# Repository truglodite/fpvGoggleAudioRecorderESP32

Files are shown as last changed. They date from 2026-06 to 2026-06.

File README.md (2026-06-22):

# fpvGoggleAudioRecorderESP32
## An easy to use reliable audio recording device for FPV goggles

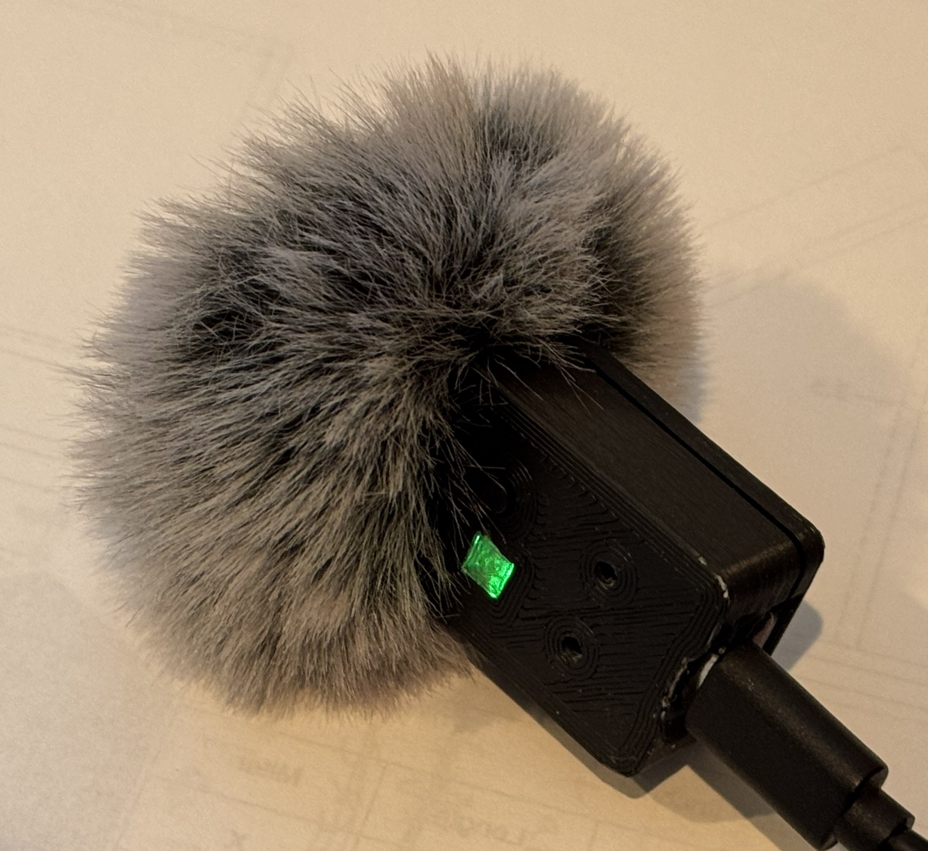
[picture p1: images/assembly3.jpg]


### Features:
- Easy to use "plug and forget" fully automated recording to sd card
- Powered via goggle USB charging jack
- 24bit-44khz audio pipeline
- DSP filter with RMS AGC and clipping limiter (pre-tuned, user adjustable)
- Robust and efficient dual core separated audio and sd write engines
- Corruption resistant raw PCM recording format and sd write methods
- "Start new segment file" button
- Easy to use Raw->Wav file converter app for PC
- Compact printable enclosure

### Hardware:
*Prefer no pins installed if using the printable enclosure*
- ESP32 S3 Super Mini Board: https://www.amazon.com/dp/B0GFDSK5RD
- ICS43434 I2S Microphone Board: https://www.amazon.com/ICS43434-Microphone-Breakout-Module-Filter/dp/B0FMDGRM8F
    * Note that almost any i2s mic (like INMP441) could be substituted in place of an ICS43434. The ICS mic is recommended as it has high dynamic range and sensitivity for the price point. Also the printed enclosure is designed to fit the above linked ICS mic board (square, not round style).
- Micro SD Card Board (3.3V): https://www.amazon.com/WWZMDiB-Module-Adapter-Memory-Shield/dp/B0BV8ZQ81F
    * I recommend removing the 4 resistors on the SD card board. Leaving the resistors on may cause problems with certain SD cards.
- 6mm Momentary NO Tactile Button: https://www.amazon.com/Momentary-Tactile-Through-Breadboard-Friendly/dp/B07WF76VHT
- 10mm Microphone Wind Screen: https://www.amazon.com/dp/B07BQ2LZDX
- SD card: https://www.amazon.com/dp/B07FCMBLV6
    * A high quality A2/U3 rated SD card is highly recommended for trouble free operation. Sandisk Extreme or Samsung Pro Plus have been tested and work well. These SD cards are generally shipped with exFAT formatting, which will not work with this project. The SD card must be formatted to fat32.

### Operation
Simply plug a USB-C to USB-C cable between the recorder and your goggle charging jack, and fly as usual. This has been tested with DJI goggles 1, 2, and 3. Fully automated recording should also work with any goggles that output 5V only while turned on.

Audio will start recording when you power on your goggles, and recording will stop when you power them off. If you want to start a new segment file while recording, click the button. This can be useful if for example you have to wait a while for GPS satellites before launching. Then less jogging is required for A/V sync in your editor.

The code makes use of the onboard LED to indicate status. A blue LED to indicates boot status immediately after powering on. While recording, a green pulsating LED with an occasional red LED will indicate normal recording and clipping limiter operation. After a button press, a blue LED will briefly light to indicate a the current segment file is closed and a new segment file is started. A repeated flashing red led indicates a failure (usually the SD card has come loose or otherwise failed). An orange flashing LED indicates the audio buffer is falling behind (extremely rare).

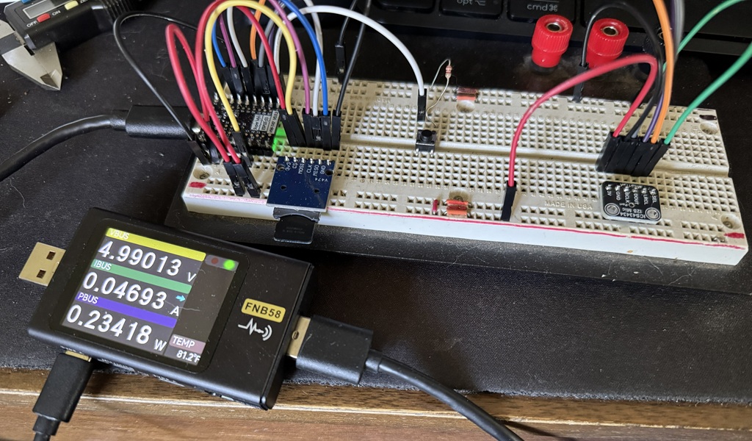
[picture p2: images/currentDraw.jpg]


The circuit averages ~50mA current draw while recording. Operating the recorder with a standard goggle battery will not appreciably decrease run time.

### Recording Format:
Similar to how a dashcam/bodycam works, this code records audio to 24bit 44khz raw PCM files which are not prone to corruption on sudden power loss. When power is cutoff, typically only the last 0-200msec of audio are lost; in a rare worst case event the last ~1.7sec may be lost. The files are named "rec_X-Y.24bit.raw", where X is the recording session, and Y is the audio segment. Both X and Y increment to allow sequential reconstruction recordings. A new segment file is created within a session after every ~2min of recording, or after the new segment file button is pressed. Code design ensures no gaps in audio between segment files. New sessions are created after power cycles.

The code makes use of a DSP filter with HPF, RMS audio compressor, and clipping limiter, which are tuned for recording "ambient voice and noise". Users can modify DSP parameters to suit their specific needs by editing values of the 7 `#defines` located at the top of the code. These parameters have comments on usage for those not familiar with DSP technical details. In general the tuning the DSP will involve balancing distant noises with background hiss to suit personal tastes.

### Post Processing:
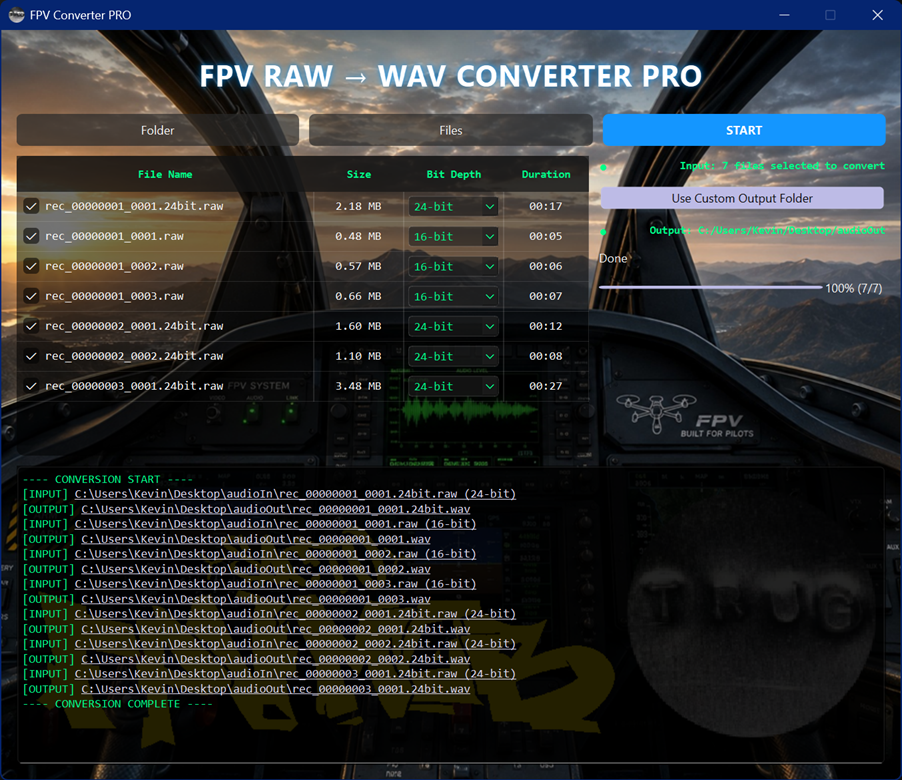
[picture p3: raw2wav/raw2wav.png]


For convenience I created `raw2wav.exe`, a Windows executable that converts batches of raw files recorded with the fpvGoggleAudioRecorderESP32 into easy to use wav files (raw2wav.exe, in raw2wav/dist/). To use the converter, run the `raw2wav.exe`, select the input folder (your SD card) and optionally an output folder. If any of the loaded files do not need conversion, uncheck the box next to them in the file selector area. Click the "Start" button to convert the selected files. The log area near the bottom shows which files are being converted and where the converted files are saved. You can click an output path in the log area to open the output folder in explorer. 

The input file list has drop down boxes for audio resolution. 16bit is there for my older RP2040 based goggle recorder project. The app will automatically select the correct 16bit or 24bit resolution based on the presence or absence of "24bit" in the filename.

Note that raw2wav.exe does not actually modify the audio content; it simply adds wav headers to the raw data and saves the files with a `*.wav` extension. Alternatively, you can do your conversions using a program like Audacity to "import raw data", "24bit unsigned", "little endian", "mono", with "44100hz" bit rate, and export to a wav file. If you do not want to use the included executable, you can compile the source using python. The compile command I used is written at the top of `raw2wav.py`.

### Logging:
A `manifest.log` file is saved to the sd card for troubleshooting purposes. Below is an example of lines that may be appended to the log (note that CLOSE and METADATA lines are written only when either a segment last longer than ~2min, or when the new segment button is used):

```
OPEN,/rec_00000001_0001.24bit.raw,12405
CLOSE,/rec_00000001_0001.24bit.raw,132405
METADATA,/rec_00000001_0001.24bit.raw,PEAK=7842100,OVERRUNS=0,AVG_QUEUE=1.42,POOL_LEAKS=0,16586
```

- OPEN/CLOSE: The millisecond timer value when a segment file starts or stops. Calculating sequential `OPEN time - CLOSE time` can help diagnose time stretching/drifting within a file (often caused by overheating or an imprecise XTAL oscillator). Similarly, sequential file `CLOSE time - OPEN time` calculation can pinpoint recording "blind spots" between files (typically caused by poor SD card performance).
- PEAK: Tells you the highest 24bit dynamic audio level recorded in that file segment ($0$ to $8,388,607$). During typical use this should be roughly `2000000` to `6000000`, indicating proper AGC tuning for the application. If this value is very low (`~300,000`) or high (`~8000000`), it indicates poor utilization of the available dynamic range from the audio engine. Your DSP parameters (or choice of mic) may not be well suited to your application, and tweaking these items may help.
- OVERRUNS: The number of dropped audio blocks. This value should remain 0. Consistent non-zero values indicate an out of spec (not A2/U3) SD card that is struggling to keep up with sustained writes.
- AVG_QUEUE: Represents the running average depth of the queue over time. A healthy value sits between 0.5 and 2.0. If this numbers climbs up to 15.0 or 30.0 on a file, it indicates high SD card write latency, which may affect the reliability of recordings.
- POOL_LEAKS: The number of audio core crashes. This should remain zero. This part contains 2 values, X,Y. X represents the number of audio core crashes that resulted in a lost audio block, and Y is the total number of blocks that have passed through the capture queue. Similar to OVERRUNS, a non-zero X indicates a slow or defective SD card. POOL_LEAKS can also indicate very high DSP overhead; this has not been observed with the default DSP configuration and range of parameters recommended in the code comments.

### Flashing/Compiling:
I recommend using VSCode with the PlatformIO extension to compile and upload this code to your ESP32 board. Download and unzip this repo to your `Projects` folder. Use the "Open Project" button in PlatformIO home and select the `fpvgoggleaudiorecorderesp32-main` folder. Connect your esp32 to a USB port on your PC, and click the upload button to compile and upload the firmware to your ESP32 (right arrow button on the bottom bar in VSCode). Further details on setting up and using PlatformIO are beyond the scope this repo.

### Wiring:
Connect the hardware together as shown in the table below.

Device  |   Pin |   ESP32 Pin
----|-----|----
MIC |   SEL |   GND
MIC |   LRCL |   4
MIC |   BCLK |   5
MIC |   DOUT |   6
MIC |   GND |   GND
MIC |   3V |   3v3
SD |   GND |   GND
SD |   MISO |   1
SD |   MOSI |   2
SD |   CLK |   3
SD |   CS |   10
SD |    3v3 |   3v3
BUTT |   A |   7
BUTT |   B  |   GND

### Printable Enclosure:

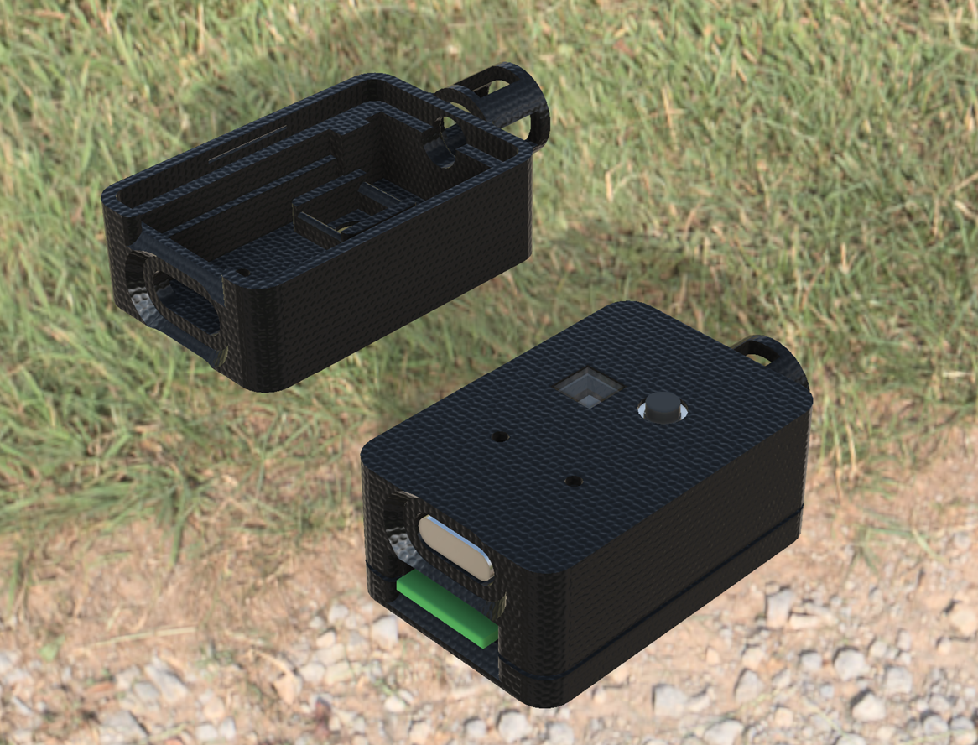
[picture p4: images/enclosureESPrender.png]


Files for a printable enclosure are provided in this repo. One of each part should be printed. Print the "agcRecorderTopWindscreen.stl" if you want to use a 10mm foam or furry wind screen on your mic. ABS or PETG is recommended for the top, bottom, and shim. Clear PETG filament or clear SLA resin should be used for the lens. I recommend using T-7000 adhesive on all of the glue joints described below.

Test fit all of the parts before wiring and assembling with glue. Make sure you can fit a toothpick or similar insulated rod through the 2 button access holes on the top of the case; cut them larger if needed. Break off the unused pins on one side of your button to prevent shorting. Insert the button into the enclosure top with pins facing the mic hole. Insert the lens into the square hole next to the button. Insert the mic board into the enclosure top, pin holes first, with the mic hole facing outward. Insert the ESP32 board into the enclosure top. Insert the SD card into it's spot on the bottom of the case, with the bare side of the board pointing downward. Snap the top and bottom halves together, making sure they fully engage. There should be a ~0.5mm gap bewteen them when fully seated. If this gap is crooked or too large, adjust fit/reprint as needed. If everything fits well, disassemble and move on to wiring.

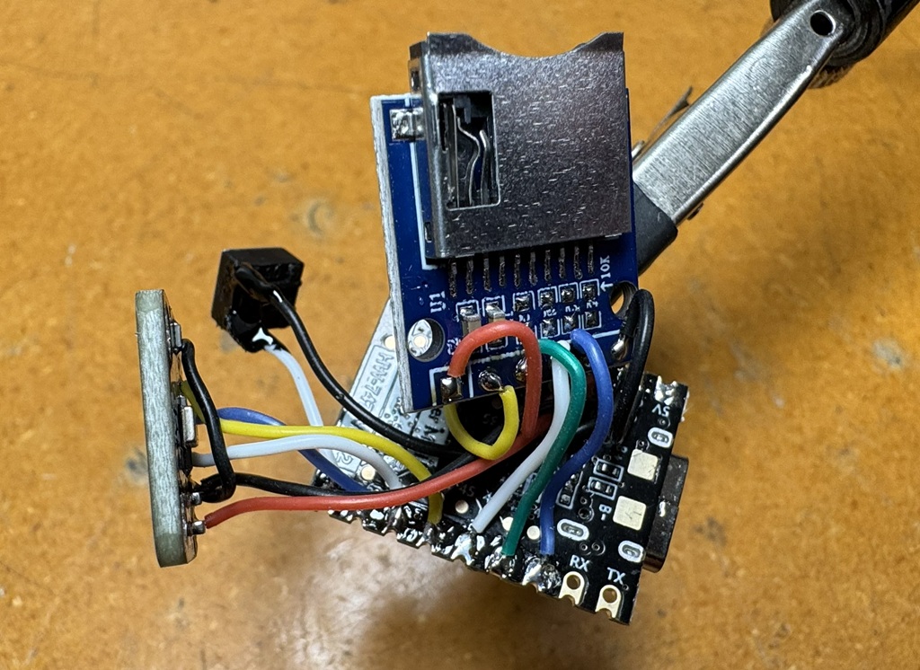
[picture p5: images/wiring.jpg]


Tidy wire routing is important as the enclosure is compact. Silicone stranded 30awg wire or smaller is recommended. Cut the wires long enough to permit assembly without tension, but not so long that assembly may pinch a wire. Start with soldering wires to the back side of the ESP32 board (opposite of boot/reset buttons). The 3 GND wires and 2 3v3 wires can be solder on the larger pads of the ESP32; it's easiest to strip and twist these wires together before tinning and soldering the bundles on the pads. Cut/solder wires to the button pins and coat the joints with glue. Cut/solder wires to the chip side of the microphone, adding a short jumper wire between the SEL and GND pins. Cut/solder wires to the top (card side) of the SD card board. Power up the circuit and verify proper operation after soldering is complete. If it records audio properly, proceed with the rest of the assembly.

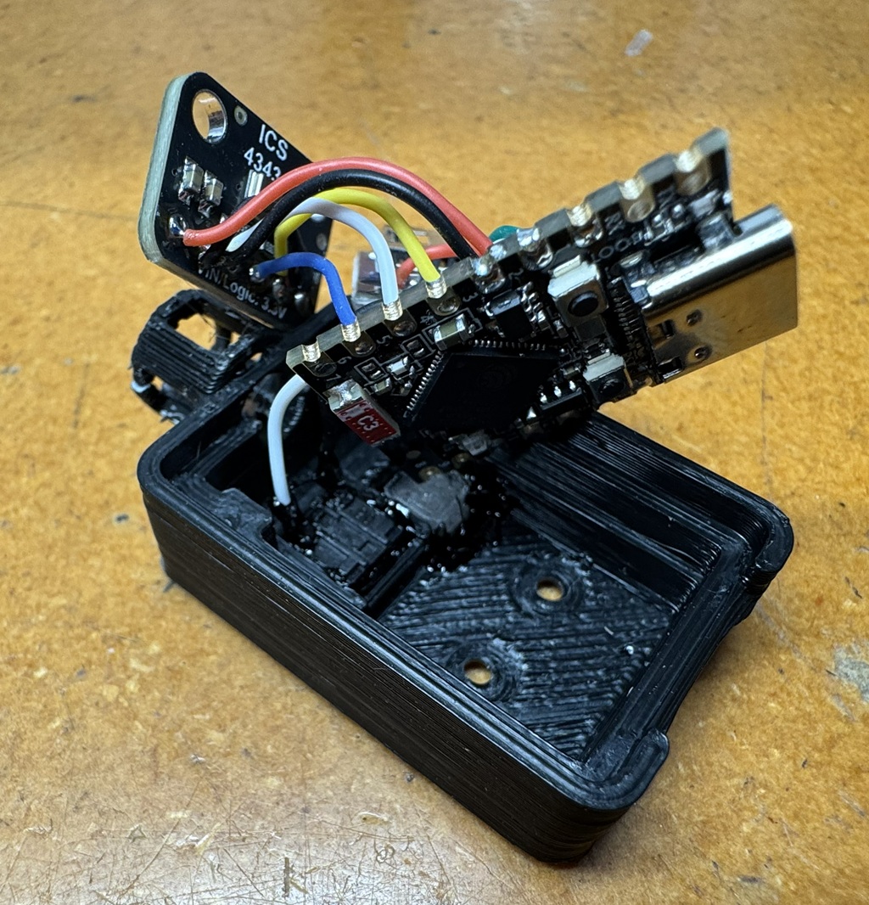
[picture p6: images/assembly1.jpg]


 First add a fillet of glue around the inside edges of the lens you pressed in earlier. Next glue the button into place; use a small amount at first to avoid squirt out that may interfere with operation. Hold the button firmly in position until the glue tacks up. Add glue to the rails where the ESP32 will sit, and press the ESP into the rails. Add a fillet of additional glue on top of the board where it touches the rails, and hold it in place until the glue tacks up. Repeat this procedure to glue the SD card in the bottom half of the case. Insert the mic into the top half of the case, adding a small amount of glue to the rails to prevent movement. Now snap the case halves together taking care not to pinch any wires. Finally, add a thick bead of glue around the bottom of the windscreen basket where it touches the box and install the windscreen, pressing it firmly down into the glue.

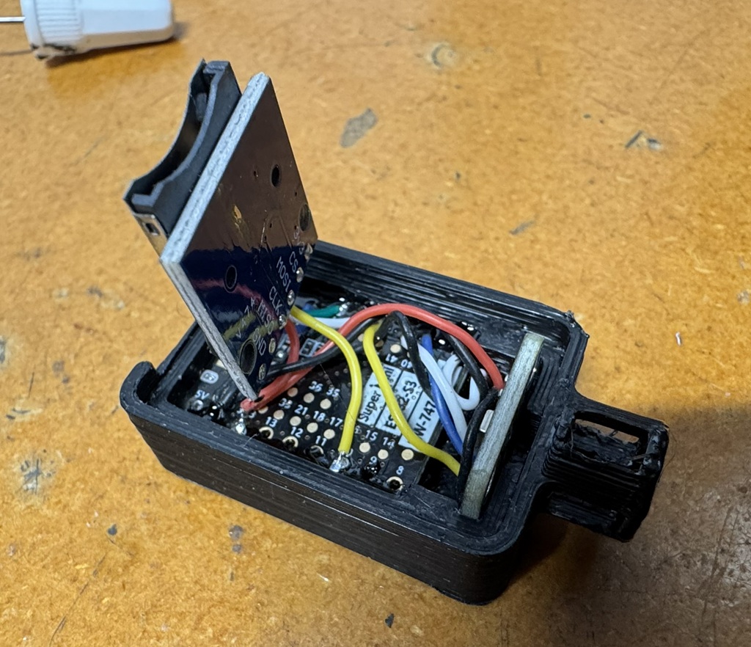
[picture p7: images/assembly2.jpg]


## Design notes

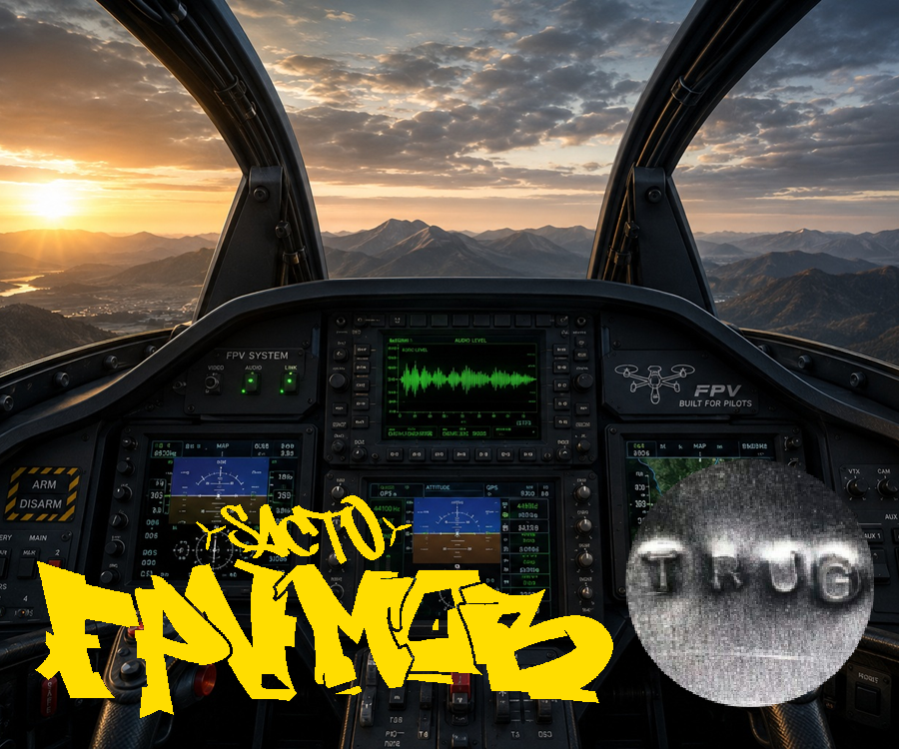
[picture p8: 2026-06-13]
raw2wav/background.png

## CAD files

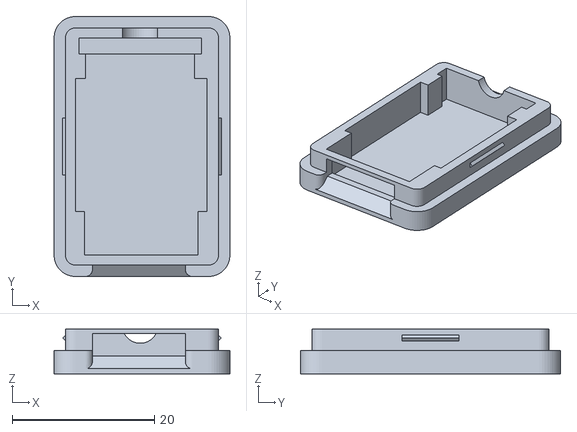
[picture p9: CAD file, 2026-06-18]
enclosure/fpvGoggleAudioRecorderESPbottom.stl
24.7 x 36.6 x 6.29

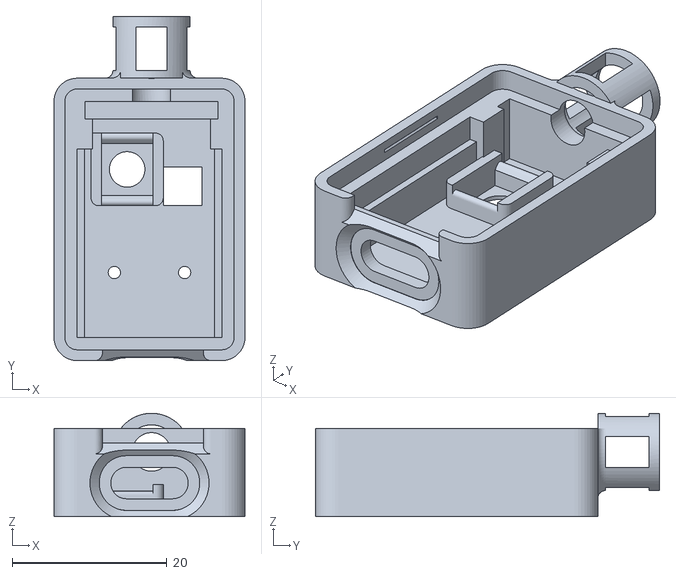
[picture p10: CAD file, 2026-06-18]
enclosure/fpvGoggleAudioRecorderESPtop.stl
24.7 x 44.6 x 13.4

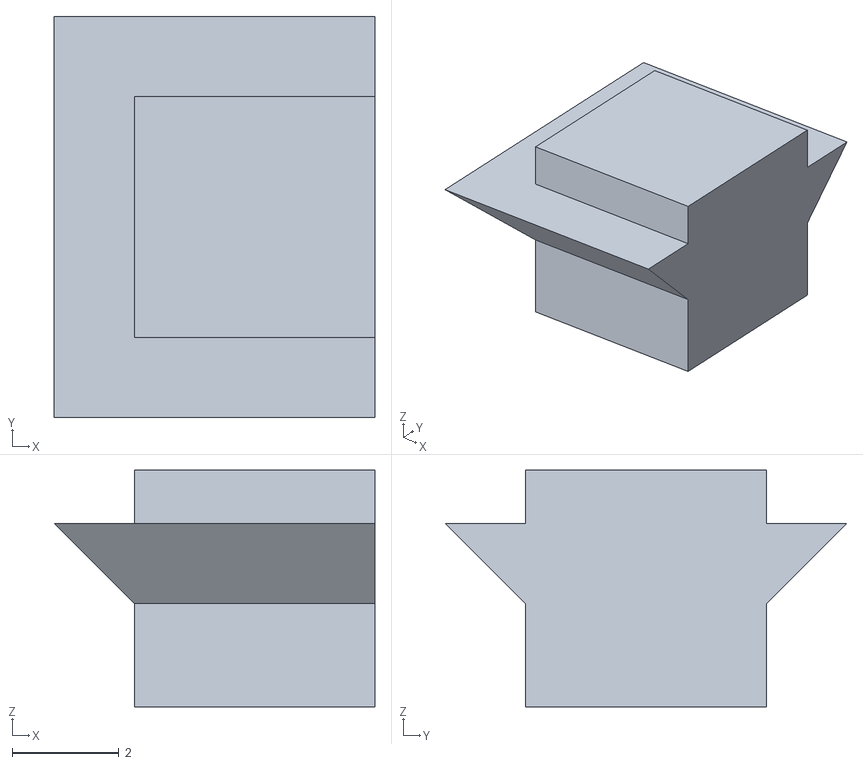
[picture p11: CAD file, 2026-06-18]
enclosure/fpvGoggleAudioRecorderESPlens.stl
6.00 x 7.50 x 4.43

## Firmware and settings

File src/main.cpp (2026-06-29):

/*
    fpvGoggleAudioRecorderESP32
    Production-oriented FPV goggle audio recorder

    Hardware:
    - ESP32-S3 Super Mini (v0.02 4MB Flash Revision)
    - ICS43434 I2S microphone (True 24-bit Audio Capture)
    - SPI microSD Slot (Configured on 100% safe edge pins)
    - Momentary Segment Button on GPIO 7 (Active Low, Internal Pullup)
    - Onboard WS2812 RGB LED on GPIO 48 (Hardware Driven via Freenove)

    Audio Architecture:
    - Dedicated FreeRTOS Audio Task pinned strictly to Core 1 (APP_CPU)
    - Disk Writing, File Operations, and UI handling locked to Core 0 (PRO_CPU)
    - Format: RAW 24-bit PCM, Signed little-endian (3 Bytes per sample), 44100 Hz mono
    - Hardware Floating-Point Unit (FPU) Optimized DSP chain
*/

#include <Arduino.h>
#include <SPI.h>
#include <SD.h>
#include <driver/i2s.h>
#include <Freenove_WS2812_Lib_for_ESP32.h>
#include <math.h>
#include <atomic>

// ======================================================
// DSP & AGC (AUTOMATIC GAIN CONTROL) CONFIGURATION
// ======================================================

// High-Pass Filter cutoff frequency in Hz.
// The alpha coefficient is derived as expf(-2π·fc/fs) — exact 1st-order RC HPF.
// [Recommended Range: 35.0f to 140.0f Hz]
// - 35.0f:  Very gentle cut (~0.995 alpha). Lets wind rumble through.
// - 85.0f:  Standard vocal mic cutoff. Blocks breath plosives. (matches original 0.988)
// - 140.0f: Aggressive wind reduction. Voices sound thin/tinny above this.
#define DSP_HPF_HZ 85.0f

// Envelope follower attack time constant in seconds (how fast gain clamps on loud peaks).
// The alpha is derived as expf(-1/(tau · block_rate)) where block_rate = SAMPLE_RATE/BLOCK_SAMPLES.
// [Recommended Range: 0.005f to 0.200f seconds]
// - 0.005f (~5ms):   Near-instant clamping. Catches hard transients, can sound clicky.
// - 0.055f (~55ms):  Original behavior (was alpha=0.900). Natural vocal limiting.
// - 0.200f (~200ms): Slow attack. Lets sharp peaks through before clamping.
#define DSP_ATTACK_S 0.055f

// Envelope follower release time constant in seconds (how fast gain recovers after a peak).
// [Recommended Range: 0.0001f to 4.000f seconds]
// - 0.0014f (~1.4ms): Instant recovery. Background noise snaps up instantly between words.
// - 1.500f (~1.5s):  Sweet spot. Background tracks up naturally between sentences.
// - 4.000f (~4s):    Slow broadcast-style glide. Very stable but slow to chase level drops.
#define DSP_RELEASE_S 0.0014f

// Threshold (dB): Audio levels above this are compressed down.
// Lower values make quieter noises louder.
// [Recommended Range: -50.0f to -20.0f]
// - -20.0f: Standard peak limiter. Only affects your voice when you actively shout.
// - -40.0f: Sweet spot for AGC. Squashes normal voice so makeup gain lifts the background. (default)
// - -50.0f: Extreme sensitivity. Will start compressing ambient room noise and floor hiss.
#define DSP_COMP_THRESHOLD_DB -50.0f

// Ratio: How aggressively loud audio is squashed above the threshold.
// [Recommended Range: 2.0f to 20.0f]
// - 2.0f: Gentle leveling. Sounds natural, but loud shouts might still clip.
// - 5.0f: Standard AGC ratio. Keeps vocal tracking relatively flat. (default)
// - 20.0f: Hard brickwall limiting. Absolute volume ceiling; can sound crushed/distorted.
#define DSP_COMP_RATIO 5.0f

// Makeup Gain (dB): The volume boost applied to the entire signal after compression.
// Decreasing threshold or increasing ratio will require increasing makeup gain.
// [Recommended Range: 10.0f to 60.0f, default = 30]
// - 10.0f: Subtle boost. Good if you only care about your own voice.
// - 30.0f: Sweet spot. Pulls distant conversations up to sound nearby.
// - 40.0f: Extreme gain. Silent field sounds like a wall of white noise.
#define DSP_MAKEUP_GAIN_DB 49.0f

// Absolute brickwall limit to prevent 24-bit integer overflow/wrap-around.
// [Recommended Range: 8000000.0f to 8388600.0f]
// - Do not exceed 8388607.0f (theoretical 24-bit max).
// - Default 8300000.0f leaves a safety margin against digital wrap-around pops.
#define DSP_LIMIT_MAX 8300000.0f

// Compile time pre-calculations
#define DSP_HPF_COEFF expf(-2.0f * (float)M_PI * DSP_HPF_HZ / (float)SAMPLE_RATE)
#define DSP_ATTACK_COEFF expf(-1.0f / ((float)SAMPLE_RATE / (float)BLOCK_SAMPLES * DSP_ATTACK_S))
#define DSP_RELEASE_COEFF expf(-1.0f / ((float)SAMPLE_RATE / (float)BLOCK_SAMPLES * DSP_RELEASE_S))

// ======================================================
// SYSTEM CONFIGURATION
// ======================================================

#define SAMPLE_RATE            44100
#define BLOCK_SAMPLES          256
#define QUEUE_BLOCKS            128
#define QUEUE_WARN_THRESHOLD_HIGH (QUEUE_BLOCKS * 85 / 100)
#define QUEUE_WARN_THRESHOLD_LOW  (QUEUE_BLOCKS * 10 / 100)

#define SEGMENT_MS             120000UL
#define FLUSH_INTERVAL_MS      1000UL   // Must be <= SD_SPACE_CHECK_MS

#define SD_CONSECUTIVE_OK_CLEAR 16

#define SD_FREE_BYTES_MIN  (64ULL * 1024 * 1024)   // ~64 MB safety margin
#define SD_SPACE_CHECK_MS  5000UL

// Pin numbers for wiring
#define SD_MISO            1
#define SD_MOSI            2
#define SD_SCK             3
#define SD_CS              10

#define RGB_LED_PIN        48  // Built-in LED
#define BUTTON_PIN         7

#define I2S_BCLK_PIN       5
#define I2S_WS_PIN         4
#define I2S_DATA_PIN       6
#define I2S_NUM            I2S_NUM_0

#define CORE1_TIMEOUT_MS   2000

// ======================================================
// RUNTIME SYSTEM STATES
// ======================================================

enum LedMode {
    LED_BOOT,
    LED_RECORDING,
    LED_WARN,
    LED_FATAL
};

volatile LedMode ledMode = LED_BOOT;

std::atomic<uint32_t> globalPeak{0};
std::atomic<uint32_t> lastAudioMs{0};       // FIX 12: atomic — written Core 1, read Core 0
std::atomic<uint32_t> core1Heartbeat{0};    // FIX 11: all writes use explicit .store()
std::atomic<uint32_t> segmentPeak{0};
volatile uint32_t     lastFileSplitMs = 0;  // Core 0 only — volatile sufficient

volatile bool fatalState    = false;
volatile bool sdWarning     = false;
volatile bool bufferWarning = false;
volatile bool diskFull      = false;
std::atomic<bool> recording{false};
std::atomic<bool> rolloverPending{false};
std::atomic<bool> limiterActive{false};

Freenove_ESP32_WS2812 statusLED(1, RGB_LED_PIN, 0, TYPE_GRB);

// ======================================================
// OS-MANAGED DUAL-CORE AUDIO RING POOL
// ======================================================

struct AudioBlock {
    int32_t samples[BLOCK_SAMPLES];
};

AudioBlock    queueBuffer[QUEUE_BLOCKS];
QueueHandle_t freeBlockQueue   = NULL;
QueueHandle_t filledBlockQueue = NULL;

// ======================================================
// FILE I/O AND METADATA TELEMETRY FIELDS
// ======================================================

File audioFile;
File manifestFile;
char currentFilename[64];

uint32_t          sessionId      = 0;
uint32_t          segmentId      = 0;
volatile uint32_t segmentStartMs = 0;  // FIX 15: volatile — read in loop(), written in openSegment()

uint32_t segmentStartOverruns = 0;
std::atomic<uint32_t> segmentQueueSum{0};
std::atomic<uint32_t> segmentQueueSamples{0};

// FIX 10: File-scope so openSegment() can reset it at every segment boundary.
uint32_t consecutiveOkWrites = 0;

struct SystemHealth {
    std::atomic<uint32_t> bufferOverruns{0};
    std::atomic<uint32_t> i2sTimeouts{0};
    std::atomic<uint32_t> sdErrors{0};
    std::atomic<uint32_t> writes{0};
    std::atomic<uint32_t> poolLeaks{0};   // FIX 13: pool slots lost when both queues are full
};
SystemHealth sys;

TaskHandle_t AudioCoreTaskHandle = NULL;

struct DSPState {
    float hp       = 0.0f;
    float prev     = 0.0f;
    float inputEnv = 0.0f;
    std::atomic<float> env{0.0f};
};
DSPState dsp;

// ======================================================
// PEAK TRACKING
// ======================================================

inline void updatePeak24(int32_t sample) {
    uint32_t a = (sample < 0) ? -(uint32_t)sample : (uint32_t)sample;

    // FIX 6: Multiplicative decay — rate-independent of block size / call frequency.
    uint32_t peak = globalPeak.load(std::memory_order_relaxed);
    if (a > peak) {
        globalPeak.store(a, std::memory_order_relaxed);
    } else {
        globalPeak.store((uint32_t)(peak * 0.999f), std::memory_order_relaxed);
    }

    // Lock-free CAS loop — safely races with Core 0's openSegment() reset.
    uint32_t cur = segmentPeak.load(std::memory_order_relaxed);
    while (a > cur) {
        if (segmentPeak.compare_exchange_weak(cur, a, std::memory_order_relaxed)) break;
    }
}

// ======================================================
// LIGHTWEIGHT UI DRIVER
// ======================================================

void updateLED() {
    static uint32_t lastUpdate = 0;
    if ((millis() - lastUpdate) < 50) return;
    lastUpdate = millis();

    static uint32_t redAlertExpiryMs = 0;
    static float    rollingMax       = 100.0f;

    rollingMax *= 0.995f;
    if (rollingMax < 100.0f) rollingMax = 100.0f;

    // FIX 1: Explicit atomic load.
    float currentEnv = dsp.env.load(std::memory_order_relaxed);
    if (currentEnv > rollingMax) rollingMax = currentEnv;

    if (currentEnv > (rollingMax * 0.85f) && currentEnv > 500.0f) {
        redAlertExpiryMs = millis() + 500;
    }
    if (limiterActive.exchange(false, std::memory_order_relaxed)) {
        redAlertExpiryMs = millis() + 500;
    }

    if (fatalState || diskFull) {
        ledMode = LED_FATAL;
    } else if (sdWarning || bufferWarning) {
        ledMode = LED_WARN;
    } else if (recording) {
        ledMode = LED_RECORDING;
    }

    switch (ledMode) {
        case LED_BOOT:
            statusLED.setLedColor(0, 0, 0, 150);
            break;

        case LED_FATAL: {
            static bool toggle = false;
            toggle = !toggle;
            statusLED.setLedColor(0, toggle ? 255 : 0, 0, 0);
            break;
        }

        case LED_WARN: {
            static uint8_t slowToggle = 0;
            if (++slowToggle > 10) {
                slowToggle = 0;
                static bool wToggle = false;
                wToggle = !wToggle;
                statusLED.setLedColor(0, wToggle ? 200 : 0, wToggle ? 100 : 0, 0);
            }
            break;
        }

        case LED_RECORDING: {
            uint32_t now = millis();
            if ((now - lastFileSplitMs) < 600) {
                statusLED.setLedColor(0, 0, 0, 255);     // Blue on file split
            } else if (now < redAlertExpiryMs) {
                statusLED.setLedColor(0, 255, 0, 0);     // Red on high volume or clip
            } else if ((now - lastAudioMs.load(std::memory_order_relaxed)) < 250) {
                // FIX 12: .load() — lastAudioMs is atomic.
                statusLED.setLedColor(0, 0, (now % 1000 < 150) ? 150 : 20, 0);
            } else {
                statusLED.setLedColor(0, 50, 0, 50);     // Purple standby/idle
            }
            break;
        }
    }
}

void fatalError() {
    fatalState = true;
    if (audioFile)    audioFile.close();
    if (manifestFile) manifestFile.close();
    while (1) {
        updateLED();
        delay(50);
    }
}

// ======================================================
// MANIFEST AND FILE STORAGE LOGISTICS
// ======================================================

void openManifest() {
    manifestFile = SD.open("/manifest.log", FILE_APPEND);
    if (!manifestFile) fatalError();
    manifestFile.print("SESSION_START_24BIT,");
    manifestFile.println(millis());
    manifestFile.flush();
}

void logEvent(const char *type, const char *name) {
    if (!manifestFile) return;
    manifestFile.print(type);
    manifestFile.print(",");
    manifestFile.print(name);
    manifestFile.print(",");
    manifestFile.println(millis());
    manifestFile.flush();
}

uint32_t loadSessionCounter() {
    uint32_t id = 0;
    if (SD.exists("/session.dat")) {
        File f = SD.open("/session.dat", FILE_READ);
        if (f) {
            if (f.available() >= (int)sizeof(id)) {
                f.read((uint8_t *)&id, sizeof(id));
            }
            f.close();
        }
    }
    id++;
    File f = SD.open("/session.dat", FILE_WRITE);
    if (f) {
        f.write((uint8_t *)&id, sizeof(id));
        f.flush();
        f.close();
    }
    return id;
}

void openSegment() {
    segmentId++;
    snprintf(currentFilename, sizeof(currentFilename),
             "/rec_%08u_%04u.24bit.raw", sessionId, segmentId);
    audioFile = SD.open(currentFilename, FILE_WRITE);
    if (!audioFile) fatalError();

    uint32_t now      = millis();
    segmentStartMs    = now;
    lastFileSplitMs   = now;

    segmentPeak.store(0, std::memory_order_relaxed);
    segmentStartOverruns = sys.bufferOverruns.load(std::memory_order_relaxed);
    segmentQueueSum.store(0, std::memory_order_relaxed);
    segmentQueueSamples.store(0, std::memory_order_relaxed);

    consecutiveOkWrites = 0;

    logEvent("OPEN", currentFilename);
}

void closeSegment() {
    if (!audioFile) return;
    audioFile.flush();
    audioFile.close();
    logEvent("CLOSE", currentFilename);

    uint32_t overrunsInSegment =
        sys.bufferOverruns.load(std::memory_order_relaxed) - segmentStartOverruns;

    // FIX 7: Explicit .load() on atomics before arithmetic.
    uint32_t qs  = segmentQueueSamples.load(std::memory_order_relaxed);
    uint32_t qsu = segmentQueueSum.load(std::memory_order_relaxed);
    float    avgQueueDepth = (qs > 0) ? (float)qsu / qs : 0.0f;

    if (manifestFile) {
        manifestFile.print("METADATA,");
        manifestFile.print(currentFilename);
        manifestFile.print(",PEAK=");
        manifestFile.print(segmentPeak.load(std::memory_order_relaxed));
        manifestFile.print(",OVERRUNS=");
        manifestFile.print(overrunsInSegment);
        manifestFile.print(",AVG_QUEUE=");
        manifestFile.print(avgQueueDepth, 2);
        manifestFile.print(",POOL_LEAKS=");
        manifestFile.print(sys.poolLeaks.load(std::memory_order_relaxed));
        manifestFile.print(",");
        manifestFile.println(millis());
        manifestFile.flush();
    }
}

bool queueEmpty() {
    return (uxQueueMessagesWaiting(filledBlockQueue) == 0);
}

uint32_t queueUsed() {
    return uxQueueMessagesWaiting(filledBlockQueue);
}

// ======================================================
// DEDICATED CORE 1 HIGH-PRIORITY AUDIO CAPTURE LOOP
// ======================================================

void audioCoreTask(void *pvParameters) {
    size_t  bytesRead = 0;
    int32_t rawSamples[BLOCK_SAMPLES];

    while (1) {
        core1Heartbeat.store(millis(), std::memory_order_relaxed);

        if (!recording) {
            vTaskDelay(pdMS_TO_TICKS(1));
            continue;
        }

        AudioBlock *block = NULL;
        if (xQueueReceive(freeBlockQueue, &block, 0) != pdTRUE) {
            sys.bufferOverruns.fetch_add(1, std::memory_order_relaxed);  // FIX 16
            bufferWarning = true;
            vTaskDelay(pdMS_TO_TICKS(1));
            continue;
        }

        esp_err_t err = i2s_read(I2S_NUM, &rawSamples, sizeof(rawSamples),
                                  &bytesRead, pdMS_TO_TICKS(20));

        if (err != ESP_OK || bytesRead == 0) {
            sys.i2sTimeouts.fetch_add(1, std::memory_order_relaxed);  // FIX 16
            memset(block->samples, 0, sizeof(block->samples));
        } else {
            size_t totalSamples = bytesRead / sizeof(int32_t);

            float maxBlockVal = 0.0f;
            for (size_t i = 0; i < totalSamples; i++) {
                float s = fabsf((float)(rawSamples[i] >> 8));
                if (s > maxBlockVal) maxBlockVal = s;
            }

            if (maxBlockVal > dsp.inputEnv) {
                dsp.inputEnv = (1.0f - DSP_ATTACK_COEFF)  * dsp.inputEnv
                             + DSP_ATTACK_COEFF  * maxBlockVal;
            } else {
                dsp.inputEnv = (1.0f - DSP_RELEASE_COEFF) * dsp.inputEnv
                             + DSP_RELEASE_COEFF * maxBlockVal;
            }

            float envdB = -100.0f;
            if (dsp.inputEnv > 0.0f) {
                envdB = 20.0f * log10f(dsp.inputEnv / 8388608.0f);
            }

            float gainReductionDB = 0.0f;
            if (envdB > DSP_COMP_THRESHOLD_DB) {
                gainReductionDB = (1.0f - (1.0f / DSP_COMP_RATIO))
                                * (DSP_COMP_THRESHOLD_DB - envdB);
            }

            float blockLinearGain = powf(10.0f,
                                         (gainReductionDB + DSP_MAKEUP_GAIN_DB) / 20.0f);

            float maxProcessedBlockVal = 0.0f;
            bool  blockClipped         = false;

            for (size_t i = 0; i < BLOCK_SAMPLES; i++) {
                if (i < totalSamples) {
                    float x  = (float)(rawSamples[i] >> 8);
                    float hp = DSP_HPF_COEFF * dsp.hp + x - dsp.prev;
                    dsp.prev = x;
                    dsp.hp   = hp;

                    hp *= blockLinearGain;

                    if (hp > DSP_LIMIT_MAX) {
                        hp = DSP_LIMIT_MAX;
                        blockClipped = true;
                    } else if (hp < -DSP_LIMIT_MAX) {
                        hp = -DSP_LIMIT_MAX;
                        blockClipped = true;
                    }

                    block->samples[i] = (int32_t)hp;
                    updatePeak24(block->samples[i]);

                    float absHp = fabsf(hp);
                    if (absHp > maxProcessedBlockVal) maxProcessedBlockVal = absHp;
                } else {
                    block->samples[i] = 0;
                }
            }

            if (blockClipped) {
                limiterActive.store(true, std::memory_order_relaxed);
            }

            float prevEnv = dsp.env.load(std::memory_order_relaxed);
            dsp.env.store(0.9f * prevEnv + 0.1f * maxProcessedBlockVal,
                          std::memory_order_relaxed);
        }

        uint32_t currentQueueUsed = queueUsed();
        if (rolloverPending.load(std::memory_order_relaxed)) {
        } else if (currentQueueUsed > QUEUE_WARN_THRESHOLD_HIGH) {
            bufferWarning = true;
        } else if (currentQueueUsed < QUEUE_WARN_THRESHOLD_LOW) {
            bufferWarning = false;
        }

        if (xQueueSend(filledBlockQueue, &block, 0) != pdTRUE) {
            if (xQueueSend(freeBlockQueue, &block, 0) != pdTRUE) {
                sys.poolLeaks.fetch_add(1, std::memory_order_relaxed);
            }
            sys.bufferOverruns.fetch_add(1, std::memory_order_relaxed);
            bufferWarning = true;
        }

        segmentQueueSum.fetch_add(currentQueueUsed, std::memory_order_relaxed);
        segmentQueueSamples.fetch_add(1, std::memory_order_relaxed);

        // FIX 12: Explicit .store() — lastAudioMs is atomic.
        lastAudioMs.store(millis(), std::memory_order_relaxed);
    }
}

// ======================================================
// DISK WRITER SEQUENCER ENGINE
// ======================================================

bool writeAudioBlock24(AudioBlock &block) {
    uint8_t  packedBuffer[BLOCK_SAMPLES * 3];
    uint16_t packIndex = 0;

    for (int i = 0; i < BLOCK_SAMPLES; i++) {
        int32_t s = block.samples[i];
        packedBuffer[packIndex++] = (uint8_t)( s        & 0xFF);
        packedBuffer[packIndex++] = (uint8_t)((s >>  8) & 0xFF);
        packedBuffer[packIndex++] = (uint8_t)((s >> 16) & 0xFF);
    }

    const size_t expectedBytes = sizeof(packedBuffer);

    for (int retry = 0; retry < 3; retry++) {
        // FIX 2: Capture position before write so partial writes rewind to the
        //        correct byte — not to the ambiguous post-partial-write position.
        uint32_t writeStart   = audioFile.position();
        size_t   bytesWritten = audioFile.write(packedBuffer, expectedBytes);

        if (bytesWritten == expectedBytes) return true;
        if (bytesWritten > 0)             audioFile.seek(writeStart);

        vTaskDelay(pdMS_TO_TICKS(2));
    }
    return false;
}

void checkSdFreeSpace() {
    if (diskFull) return;                                    // FIX 14
    static uint32_t lastSpaceCheckMs = 0;
    if ((millis() - lastSpaceCheckMs) < SD_SPACE_CHECK_MS) return;
    lastSpaceCheckMs = millis();

    if ((SD.totalBytes() - SD.usedBytes()) < SD_FREE_BYTES_MIN) {
        diskFull = true;
    }
}
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
void loop() {
    checkButton();
    writeTaskStep();
    updateLED();
    checkCore1Health();
    if (diskFull) {
        closeSegment();
        fatalError();
    }
    printStats();
    vTaskDelay(pdMS_TO_TICKS(1));
}

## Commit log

2026-06-13 cleanup code, reduce FPU calcs to be reasonable for audio application, update peak led indicator, reduce SPI speed for less power and noise, use native FreeRTOS ring buffer, fix new file led indicator
    [main.cpp]
2026-06-14 Fix possible overflow at a = abs(sample), use true alpha for attack/release, fix bloating block leak, fix possible core heartbeat false-restart, add watermarking fix for queue warning, fix sd warning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
    [main.cpp]
2026-06-14 fix i2s read timeout, increase sd spi from 20Mhz to 40Mhz, fix volatile race condition, fix dspsate stale reads, fix queue reporting error, fix autio limiter, fix sd retry loop, fix queueEmpty() race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
    [main.cpp]
2026-06-18 update readme, add enclosure files
    [fpvGoggleAudioRecorderESPbottom.stl, fpvGoggleAudioRecorderESPlens.stl, fpvGoggleAudioRecorderESPtop.stl]
2026-06-18 Several bug fixes, update readme
    [main.cpp]
2026-06-18 add enclosure render image, add placeholders for images.
2026-06-21 fix 500msec gap between segments
    [main.cpp]
2026-06-23 retune dsp defaults, delete previous fix comments
    [main.cpp]
2026-06-29 comments about wiring
